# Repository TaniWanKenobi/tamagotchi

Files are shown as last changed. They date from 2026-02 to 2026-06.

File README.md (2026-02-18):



<p align="center">
  <a href="https://www.kicad.org">
    
  </a>
  <a href="https://www.onshape.com">
    
  </a>
</p>

<br />

<div align="center">
  Tamagotchi
</div>

<h3 align="center">Tamagotchi</h3>

<p align="center">
  A custom PCB-based Tamagotchi virtual pet built with the XIAO-ESP32-C6!
</p>

<details>
  <summary>Table of Contents</summary>
  <ol>
    <li>
      <a href="#about-the-project">About The Project</a>
      <ul>
        <li><a href="#built-with">Built With</a></li>
        <li><a href="#pcb-design">PCB Design</a></li>
        <li><a href="#3d-model">3D Model</a></li>
        <li><a href="#bom">BOM</a></li>
      </ul>
    </li>
    <li><a href="#contact">Contact</a></li>
  </ol>
</details>

## About The Project

<div align="center">
  CAD
</div>

A custom PCB-based Tamagotchi virtual pet built with the XIAO-ESP32-C6 microcontroller, featuring a 0.96" OLED display, three buttons, and a buzzer.

I made the project to have my own completely customizable tamagatchi! I also want you to customize yours however you want - check my [tutorial](/tutorial.md) for instructions! 

To use this, simply flash the xiao with the firmware in the repo! Here is an assembly diagram:

assembly

### PCB Design

Here is my PCB:

PCB

Front 3D model

Back 3D model

Here is the schematic used to make the PCB:

Schematic

### 3D Model

3D Model Front

Here is the [Onshape link](https://cad.onshape.com/documents/fa5791d8e7f345b436054923/w/ad8e09905eb572b0a8a40e9d/e/e81f06aa82a76dd04f8e6832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)!

### BOM

| Component | Qty | Price | Tax (6.7%) | Total | Link |
|---|-----|---|---|---|---|
| XIAO-ESP32-C6 | 1 | $5.20 | $0.35 | $5.55 | [Seeed Studio](https://www.seeedstudio.com/Seeed-Studio-XIAO-ESP32C6-p-5884.html) |
| Seeed Studio Shipping | 1 | $6.69 | $0.45 | $7.14 | — |
| 0.96" OLED Display | 1 | $2.15 | $0.14 | $2.29 | [LCSC](https://www.lcsc.com/product-detail/C5248080.html) |
| Tactile Button | 3 | $0.50 | $0.03 | $0.53 | [LCSC](https://www.lcsc.com/product-detail/C2888493.html) |
| Buzzer | 1 | $0.54 | $0.04 | $0.58 | [LCSC](https://www.lcsc.com/product-detail/C49246964.html) |
| Male Pin Headers (20 pcs) | 1 | $0.59 | $0.04 | $0.63 | [LCSC](https://www.lcsc.com/product-detail/C49261205.html) |
| LCSC Shipping | 1 | $14.73 | $0.99 | $15.72 | — |
| JLCPCB PCB | 1 | $5.40 | $0.36 | $5.76 | [JLCPCB](https://jlcpcb.com/) |
| JLCPCB Shipping | 1 | $3.30 | $0.22 | $3.52 | — |
| M3 8mm Screws | 1 | $2.28 | $0.15 | $2.43 | [AliExpress](https://www.aliexpress.us/item/3256809831708799.html) |
| Brass Threaded Inserts | 1 | $5.79 | $0.39 | $6.18 | [AliExpress](https://www.aliexpress.us/item/3256806286648221.html) |
| | | | | | |
| **Total** | | **$47.17** | **$3.16** | **$50.33** | |

## Contact

Tanishq Goyal - @Tanuki - [tanishqgoyal590@gmail.com](mailto:tanishqgoyal590@gmail.com)

<p align="right">(<a href="#readme-top">back to top</a>)</p>

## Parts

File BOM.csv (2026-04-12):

Item | Description | Quantity | Unit Price ($) | Total Price ($) | URL | Running Total ($ with Tax)
XIAO ESP32 C3 | MCU | 1 | $7.09 | $7.09 | https://www.aliexpress.us/item/3256808605622611.html | $7.56
Display | s | 1 | $1.93 | $1.93 | https://www.aliexpress.us/item/3256807544901434.html | $9.62
Headers | Headers | 1 | $1.69 | $1.69 | https://www.aliexpress.us/item/3256811506646304.html | $11.42
Buzzer | 12*9.5mm | 1 | $2.39 | $2.39 | https://www.aliexpress.us/item/3256810135642750.html | $13.97
Button | 4.5X4.5MM Button | 1 | $2.57 | $2.57 | https://www.aliexpress.us/item/3256806953793236.html | $16.71
Threaded Inserts | M3X4X5 | 1 | $2.47 | $2.47 | https://www.aliexpress.us/item/3256811754262338.html | $19.34
Screws | M3, 8mm | 1 | $2.23 | $2.23 | https://www.aliexpress.us/item/3256809831708799.html | $21.72
Shipping | Aliexpress | 1 | $2.53 | $2.53 | https://www.aliexpress.us/ | $24.42
PCB | JLCPCB | 1 | $3.20 | $3.20 | https://jlcpcb.com/ | $27.83
Shipping | JLCPCB | 1 | $3.12 | $3.12 | https://jlcpcb.com/ | $31.16

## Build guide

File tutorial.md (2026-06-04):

# Tamagotchi PCB Tutorial

> **Note:** Your schematic should NOT look like this at the end of the tutorial! You are required to add your own components and switch it up to personalize it :D

---

## Table of Contents

- [Installing KiCad](#installing-kicad)

### 1. Schematic Design
- [Creating the Schematic](#creating-the-schematic)
  - [Importing the MCU](#importing-the-mcu)
  - [Adding the OLED Display](#adding-the-oled-display)
  - [Adding Buttons](#adding-buttons)
  - [Adding a Buzzer](#adding-a-buzzer)
  - [Power & Battery Setup](#power--battery-setup)
  - [Assigning Footprints](#assigning-footprints)

### 2. PCB Design
- [Creating the PCB](#creating-the-pcb)
  - [Defining the Board Outline](#defining-the-board-outline)
  - [Component Placement](#component-placement)
- [Button Footprint Mismatch](#button-footprint-mismatch)
- [PCB Routing](#pcb-routing)
  - [Routing Traces](#routing-traces)
- [Customization](#customization)
- [Run Design Rules Check](#run-design-rules-check)
  - [Common DRC Errors](#common-drc-errors)

### 7. Files & Version Control
- [Add Your Files to Your GitHub Repo](#add-your-files-to-your-github-repo)
- [Upload Your Files to GitHub](#upload-your-files-to-github)
  - [Edit Your README](#edit-your-readme)

### 8. Fabrication
- [Getting a JLCPCB Price](#getting-a-jlcpcb-price)
  - [Settings](#settings)

### 9. Enclosure Design
- [Designing the Case](#designing-the-case)

---

## Installing KiCad

Download KiCad from the official site: **[https://www.kicad.org/download/](https://www.kicad.org/download/)**

1. Go to the download page and select your operating system (Windows, macOS, or Linux).
2. Download the latest **stable release** (KiCad 10.x).
3. Run the installer and follow the on-screen instructions (the defaults are fine).
4. When prompted, make sure to **install the default libraries** (they're selected by default).
5. Launch KiCad and create a new project (**File → New Project** or **Ctrl+N**).

What are the default libraries?

> KiCad ships with a large set of schematic symbols, PCB footprints, and 3D models. These cover most common components (resistors, capacitors, connectors, etc.) so you don't have to create them from scratch. You'll still need to import specialty parts (like the XIAO or OLED), but the defaults cover the basics.

> **New to KiCad?** Read the official getting started guide before continuing:
> [KiCad 10.0: Getting Started](https://docs.kicad.org/10.0/en/getting_started_in_kicad/getting_started_in_kicad.html)

---

## Creating the Schematic

The XIAO-ESP32-C3 will be used as the MCU in this guide! This is because it's tiny and includes WiFi, Bluetooth, and built‑in battery charging, which makes it perfect for this.

What is an MCU?

> MCU stands for **Microcontroller Unit**, the tiny computer (brain) of your project. It runs your code and controls all the other components (display, buttons, buzzer, etc.). The XIAO-ESP32-C3 is the MCU we're using here.
>
> That said, other MCUs are worth knowing about. The RP2040 is a good pick if you don't need wireless: dual-core, and has really good documentation! The nRF52840 is the go-to for low power BLE projects, with sleep currents that blow the ESP32 out of the water. For this project the C3 wins because it's affordable, has WiFi and BLE built in, and includes onboard LiPo charging so no external charger chip is needed.I use the C3 for those reasons.

Useful schematic editor keybinds

> | Key | Action |
> |-----|--------|
> | **A** | Add a symbol (component) |
> | **W** | Draw a wire |
> | **P** | Add a power symbol (VCC, GND, 3V3, etc.) |
> | **L** | Add a net label |
> | **M** | Move a component |
> | **R** | Rotate a component |
> | **G** | Grab/drag a component (keeps wires attached) |
> | **E** | Edit component properties |
> | **C** | Copy a component |
> | **Delete** | Delete selected item |
> | **Ctrl+Z** | Undo |
> | **Ctrl+S** | Save |

### Importing the MCU

First, I imported the XIAO-ESP32-C3 from the [SeeedStudio Wiki](https://wiki.seeedstudio.com/XIAO_ESP32C3_Getting_Started/). Here's an [excellent tutorial](https://www.youtube.com/watch?v=lnCvyGIQong) on using it!

I downloaded from this:



I then clicked **A** (Add Symbol), searched for the part, and imported it. I ended up with this:

Xiao

Most symbols won't label every pin with its function (SDA, SCL, MOSI, etc.) They'll just show pin numbers. When that happens, google the MCU name + "pinout" to find the official diagram and cross-reference which pin number maps to which function :D 

**Now, for this tutorial, I will create the base Tamagotchi. Spice your own Tamagotchi up more than this one! Add some flavor!**

I then connect GND to GND, 5V to +5V, 3V3 to  and BAT to + as shown below:

Power connections

## What is 5V? What is GND? What is 3V3?

> #### What "ground" actually means here
>
> Ground is the **reference point** for the entire circuit.
> Think of it as the **zero level** that everything else is measured against.
>
> - Voltage is always measured **relative to ground**.
> - Current flows **from power, through components, back to ground**.
> - Without ground, the circuit has **no return path**, so nothing works.
>
> Ground isn't "negative energy"; it's simply the **other side of the loop**.
>
> [Check this for more information!](https://www.build-electronic-circuits.com/what-is-ground/)
>
> Additionally, here's some ground!
>
> grass
>
> #### What voltage is, and why it matters
>
> Voltage is the **electrical pressure** that pushes electrons through the circuit.
>
> - Higher voltage = stronger push
> - Lower voltage = weaker push
>
> Voltage matters because every component is designed to operate within a certain range.
>
> [Check this for more information!](https://battlebornbatteries.com/what-are-volts/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)
>
> low-voltage
>
> #### 5V vs 3V3, why two rails?
>
> The XIAO exposes two voltage rails: **5V** and **3V3**.
>
> - **5V** is powered by USB-C. When running on battery, the LiPo only outputs ~3.7V, not enough to supply this pin, so it gets no power.
> - **3V3** is a stable 3.3V generated on-board, available whether you're on USB or battery.
>
> Most components, the OLED, sensors, logic pins, are rated for **3.3V**, so connect them to 3V3. Too much voltage means too much current, which damages components. 

**Why didn't I connect the top pads?**



I didn't connect them because I don't need JTAG debugging for this project. A JTAG debug cable is a special cable that connects your computer to these pads, letting you pause your program mid-run and inspect exactly what's happening inside the chip line by line. USB-C handles everything we need here.

You may use them if you want, but I didn't because it would complicate the PCB for not much benefit. You might want to use them if you have a really tricky bug that Serial printing can't help you catch, or if you run out of GPIO pins and need extras.

### Adding the OLED Display

I then added the [0.96" OLED](https://www.lcsc.com/product-detail/C5248080.html) via EasyEDA to KiCad. Follow this [guide](https://hwdocs.hackclub.dev/user-contrib-guides/easyeda2kicad/)!

I connected GND to GND, SDA to SDA, and SCL to SCL. Use **W** to draw wires between pins!

What are SDA, SCL, and GND?

> - **GND** = Ground, the common reference point for all electrical signals.
> - **SDA** = Serial Data, the line that carries data back and forth over I2C.
> - **SCL** = Serial Clock, the line that provides the timing signal for I2C communication.
>
> I2C is a protocol that lets multiple devices talk over just two wires (SDA + SCL).

Do I need pull-up resistors on SDA and SCL?

> Normally yes. I2C requires pull‑up resistors on SDA and SCL; however, the XIAO boards already include internal pull‑ups, so you don't need external ones here.

I checked the [datasheet](https://www.lcsc.com/datasheet/C5248080.pdf) attached on the LCSC page and found that VCC should be connected to 3V3.



I therefore connected it as such



### Adding Buttons

Since a Tamagotchi has three buttons, I decided to add those as well!

For this, I decided to use an **active‑low** button layout (which is the most common approach).

What does "active-low" mean?

> "Active-low" means the button is considered "pressed" when the signal goes LOW (0V / GND). When the button is not pressed, the internal pull-up resistor keeps the pin HIGH (3.3V). This is the most common button wiring approach because it's simple: you only need the button and a ground connection, no extra resistors.

Each button connects one side to **GND** and the other to a **GPIO pin** with the XIAO's **internal pull‑up** enabled. This makes the pin read **HIGH** when the button is idle, and **LOW** when the button is pressed.



What is a GPIO pin?

> GPIO stands for **General Purpose Input/Output**. These are the programmable pins on your microcontroller that can be configured as either inputs (to read sensors/buttons) or outputs (to drive LEDs/buzzers). On the XIAO, pins like D0–D10 are GPIOs.

### Adding a Buzzer

I also added a buzzer from [here](https://www.lcsc.com/product-detail/C49246964.html)!

The buzzer is wired with one pin to a GPIO output and the other to GND, letting the GPIO drive it with a square‑wave tone.



### Power & Battery Setup

I then added the battery.

The XIAO ESP32C3 has built-in battery charging, so all you need to do is connect a LiPo battery directly to the BAT pin. This lets the board run wirelessly and automatically charges the battery whenever you plug in USB-C.

BAT is connected only to the battery because it is a dedicated charging pin, separate from the main 3.3V power rail. GND however is shared across everything on the board, since all components need a common ground reference to work correctly.



> **Don't forget to place no-connect flags where there aren't connections!**

Press `Q` → click the pin to place the no-connect flag



> **Note:** In schematics, inputs are generally placed on the left and outputs on the right. This is a common convention that makes your schematic easier to read, since signal flow goes left to right just like reading a book. You don't have to follow this strictly, but it is good practice to keep things consistent!

### Assigning Footprints

This is my final schematic! Let's make the PCB now. First, let's assign parts. Click this:



Then assign the corresponding EasyEDA / OPL parts! For the buttons, import from [here](https://www.lcsc.com/product-detail/C2888493.html)!

1. **Battery connector:** I use 2.54mm male headers, since 2.54mm is the standard pin spacing used on most hobby electronics and battery connectors.
2. **Buzzer:** According to the [AliExpress listing](https://www.aliexpress.us/item/3256810135642750.html) I am ordering from, the buzzer is 12x9.5mm, where 12mm is the diameter and 9.5mm is the pin spacing. This fits the `Buzzer_12x9.5RM7.6` footprint. Note that the EasyEDA buzzer footprint uses a pin spacing of 7mm instead of 9.5mm, so make sure to use the correct one!
3. **Buttons:** Imported from the link above.
4. **XIAO:** I use a mix of SMD and DIP footprint from the [footprint library](https://files.seeedstudio.com/wiki/XIAO-KiCad-Library/New_XIAO_Series_Footprints.zip) linked earlier. I will later modify the footprint so the SMD pads are through-hole, allowing me to solder the XIAO directly by melting solder into the pads. The name of this footprint is `XIAO-ESP32-C3-DIP-SMD`.
5. **OLED:** Imported from EasyEDA using the link from earlier.

Footprint assignment

Now, press this and open the PCB viewer:

Open PCB viewer

---

## Creating the PCB

**The maximum size of your PCB should be 100mm²!**

You should see something like this:

PCB editor

To synchronize changes between your schematic and PCB layout in KiCad:

- Press **F8**, *or*
- Click the **Update PCB from Schematic** button

You can do this anytime you want to refresh the PCB with the latest schematic updates.

What are those two circles?
> Those are M3 mounting holes! Click A to add them!

### Defining the Board Outline

You'll notice a white outline surrounding the entire board. This is the **Edge Cuts** layer, which defines the physical boundary where the PCB will be cut.

This is done by modifying the `Edge.Cuts` layer on the right side. There are many ways to do this, such as manually drawing it with the given menu.

I found the default outline options limiting and wanted to create something more complex. To do this, I:

1. Drew out the edge cuts layer. I just did this on figma, you can do this anywhere!!!
2. Converted the image into a DXF file using an image-to-DXF converter.
3. Imported the DXF file into KiCad.
4. Created a 100×100 mm box as a reference.
5. Used the measuring tool to determine the correct scale.
6. Scaled the outline down so it fit within 100 mm.

cutout

You can also use the kicad tools on the right to draw a barrier, they work well! I just wanted to make a cool and unique border. You should try it!



### Component Placement

**First, I laid my PCB out in a 100×100 box.**

Place all of your components inside the board outline. Move components to shorten **ratlines**, which are the straight blue lines.

- **M**: Move a component
- **R**: Rotate a component
- **F**: Flip a component to the other side of the board
- **Ctrl+S** / **⌘+S**: Save (do this often!)

What are ratlines?

> Ratlines (also called "ratsnest lines") are the thin straight lines that show unrouted connections between pads. They indicate which pads need to be connected with copper traces. Your goal is to arrange components so these lines are as short as possible and don't cross each other, which makes routing much easier.

Heres what I ended up with!



---

## Button Footprint Mismatch

> **Always verify your footprint before finalizing your PCB layout.** Even if a component looks correct in the schematic, the footprint may have incorrect pad numbering that causes your circuit to fail silently. A common red flag: any pin without a net almost always means something went wrong during import.

### Why This Happens

After importing a button from EasyEDA into KiCad, the footprint may look fine at first glance:

KiCad imported switch footprint

EasyEDA uses a **redundant 4-pin symbol**, showing all four pins separately even though two pairs are internally shorted:

EasyEDA button symbol

KiCad uses a **cleaner 2-pin representation**:

KiCad button symbol

When imported, EasyEDA's pins 1 and 2 map to opposite footprint pads, but on a tactile switch they're on the **same physical side** (internally shorted). This means pads that should be electrically separated end up sharing a net, and the button does nothing because one side is permanently shorted to itself.

| EasyEDA pins | Physical side | KiCad net |
|:---:|:---:|:---:|
| 1, 2 | Side A (shorted) | Net 1 |
| 3, 4 | Side B (shorted) | Net 2 |

The switch connects **Side A to Side B** when pressed. The footprint must reflect this.

### Confirming with the Datasheet

Verify the pinout using the component's datasheet. If sourcing from LCSC, the datasheet is available directly on the product page. For example:

- [Product page](https://www.lcsc.com/product-detail/C2888493.html)
- [Datasheet](https://www.lcsc.com/datasheet/C2888493.pdf)

Physical pin diagram
Internal schematic

These confirm that **pads 1 and 2 are shorted** (Side A) and **pads 3 and 4 are shorted** (Side B).

### Fixing the Pad Numbering

Renumber the footprint pads to match the correct mapping:

- Pads **1 and 2** (same physical side) → renumber both to **`1`**
- Pads **3 and 4** (other physical side) → renumber both to **`2`**

1. Double-click the footprint in the PCB editor and click **Edit Library Footprint**.

Edit Library Footprint dialog

2. Double-click each pad hole and update the pad number to match the corrected mapping:

Corrected pad numbering

3. Press `Ctrl+S` to save.

### Applying the Fix

1. Go to **Tools > Update Footprint from Library**.

Update Footprint from Library menu

2. Click **Update**.

The footprint will refresh with the corrected pad numbering: one net on Side A, a separate net on Side B, and the switch bridging them when pressed.

> Does this not work? Try deleting the buttons, and updating from schematic again :)



We do something similar to the XIAO footprint.

Xiao

Double click each BAT pad, set it to through-hole (THT), and give it a drill diameter of 0.889mm.

Fixing Footprint

You may also notice that similar to the buttons, the pin numbers are wrong according to the official Seeed diagram:

Footprints

Fix the pin numbers to match. Keep in mind that the footprint is mirrored, so if it helps, temporarily move it to the back layer so it is orientated the same way as the diagram.

Here are some useful diagrams!





Here is the final result:

Final result

Save and update your PCB from schematic when done!

---

## PCB Routing

A PCB is made up of multiple layers. Our boards are "two-layer," meaning that they have two layers of copper wire.

What are the PCB layers?

> | Layer | Description |
> |-------|-------------|
> | **Top & bottom silkscreen** | The white ink layer where you can add art |
> | **Top & bottom copper** | The layers where you make your copper wires |
> | **Substrate** | The actual plastic (usually green) which makes up your board |
> | **Via** | The tunnels which connect the top and bottom copper layers |
>
> PCB layers

### Routing Traces

Now it's time to route the PCB! Hit **X** on your keyboard and click anything with a thin blue line poking out of it. It should dim the entire screen, show you which direction you need to go with a thin blue line, and highlight the destination:

Routing example

**Key routing shortcuts:**

- **X**: Start routing a trace
- **V**: Add a via (switch trace to the other side of the board mid-route)
- **Backspace**: Delete the last trace segment while routing
- **Esc**: Cancel the current route
- **D**: Drag a trace (reposition it without breaking connections)
- **U**: Select the entire trace from the point you click

Join the highlighted points together. If there isn't enough space on the front side, or there is a trace already present that is blocking you, you can route on the back side by clicking **B.Cu** on the right toolbar. If you want to change sides during routing, press **V** and a via will be added, which will transfer your trace to the other side of the board.

> **Important:** Wires and pads of different colors (except golden) can't be connected together directly! You must use a via to the other side.

What is a via?

> A via is a small plated hole that connects a copper trace on one layer of the board to a trace on another layer. Think of it as a tiny tunnel through the PCB. You use them when you can't route a trace on one side because another trace is in the way. Press **V** while routing to drop a via and continue the trace on the other side.

Your routing is complete!

Ground plane

> **Tip:** Place everything based on what shortens the blue lines, and what makes them not cross!

> **Tip:** Use a [ground plane](https://www.kicadtips.com/how-to/make-a-ground-plane) to help with routing and to reduce noise. That's what the red and blue layers are for! It's not necessary, but looks nice and is easy to set up!

> **Note:** You may notice [stitching vias](https://resources.altium.com/p/everything-you-need-know-about-stitching-vias) in my board (the small holes scattered across the ground plane). **You do NOT need to add these.** They are completely optional for a board like this!
>
> Stitching vias

---

## Customization

You may have already added some text and art to customize your board like me. If not, you can click **F.Silkscreen** and use the text tool.

Sample text

To add art, select the **Top Silkscreen Layer** or **Bottom Silkscreen Layer** in the sidebars, then use the KiCad image converter to add custom art.

KiCad image converter

Your board is now beautiful! 

---

## Run Design Rules Check

**DRC** stands for **Design Rules Check**. This runs a check that makes sure your board has no interference errors, no components are off the board, and no wires are intersecting. It does **not**, however, confirm that your board works.

DRC

Using the output, correct any errors. This can be confusing, so remember: you can always ask for help!

What are common DRC errors?

> - **Track and copper errors** : clearance violations, track width, annular rings
> - **Via errors** : diameter, micro vias, blind/buried vias
> - **Pad and footprint errors** : pad-to-pad, hole clearances
> - **Edge and board outline errors** : copper edge clearance, silkscreen issues
> - **Zone errors** : copper slivers, starved thermals, unconnected items
> - **Net and connection errors** : missing connections, net conflicts
> - **Courtyard errors** : overlaps, missing courtyards

Once your PCB passes the DRC, it is finished!

In the PCB editor, click **View → 3D Viewer** to see your finished work!

3D Viewer

> Final

---

## Add Your Files to Your GitHub Repo

Now it is time to order your board. Get the following files from your project:

- **A screenshot of your 3D view**
  - In PCB Editor: **View → 3D Viewer → Edit → Copy 3D Image**
- `.kicad_pro` (KiCad project file)
- `.kicad_sch` (schematic)
- `.kicad_pcb` (PCB layout)
- **Your Gerber files** (see below)

How do I export Gerber files?

> 1. In your PCB editor: **File → Fabrication Outputs → Gerbers (.gbr)**
> 2. Set an output folder (e.g., a new "Gerbers" folder)
> 3. Select necessary layers (generally already selected)
> 4. Click **Plot**
> 5. Click **Generate Drill Files**
> 6. Zip the resulting files for your manufacturer
>
> Gerber files are the industry-standard format that PCB manufacturers use to fabricate your board. They contain the copper layers, silkscreen, solder mask, drill locations, and board outline.

---

## Upload Your Files to GitHub

Go back to the GitHub repo you created at the start. Click **Add File → Upload files**.

Drag in your:

- Screenshot of your 3D view
- `.kicad_pro` (KiCad project file)
- `.kicad_sch` (schematic)
- `.kicad_pcb` (PCB layout)
- Gerbers (zipped)

You should have downloaded all of these in the previous step.

Click to commit your changes.

### Edit Your README

Finally, edit your README to include the submission requirements:

- A short description of what your project is
- A couple sentences on why you made the project
- A couple sentences on how to use your project

**Pictures of your project:**

- A screenshot of a full 3D model of your project
- A screenshot of your PCB, if you have one
- A wiring diagram, if you're doing any wiring that isn't on a PCB

**A BOM (Bill of Materials) in table format at the end of the README, with links.**

> **NOTE:** ALL projects you make for Blueprint must have a project photo in your README.

---

## Getting a JLCPCB Price

Go to [jlcpcb.com](https://jlcpcb.com/) and make an account. Then, add your Gerber file for the instant quote.

JLCPCB upload

### Settings

You should keep the default settings for everything. The only thing you should/can change is the **PCB Color**. I did black as seen below:

PCB color

For high-spec options, also keep the default. **Do not** click PCB assembly! 

High-spec options

Once you have successfully *not* changed any of the settings (except the board color), on the right, change the shipping method to **Global Standard Direct** (or **Air Registered Mail** if it is cheaper).

---

## Designing the Case

Export the PCB from KiCad into your CAD platform! For me, this is Onshape.

**Check [this amazing onshape tutorial](https://www.youtube.com/watch?v=d4QzBdcQoe0&list=PLGqRUdq5ULsMDOxmu10AGPDIOkzNYu7D7&index=2)!**

I googled and found headers! I found this from [here](https://www.3dcontentcentral.com/download-model.aspx?catalogid=171&id=1025256)!

I then experimented with the CAD a lot. I used revolve, but it did not look nice and was hard to use. I also tried multiple placements for the battery and found it was optimal if it's placed vertically.

To make these, I created a sketch by clicking the sketch button in the upper-left-hand side and made multiple shapes that include tolerance and my shell size.







I also decided to change the PCB to add the vibration motor to the back and raise the screen!

From



to



My headers overlapped with the buzzer, so I decided to reposition the buzzer to the middle of the board! The gap between the LCD and the headers should give me enough space!

example

I made the back portion with 3D-printed standoffs and added large fillets to round the edges. I made the top part and added some tolerance between the top of the plate and the bottom of the top half of the case!



I added a hole for the battery and a hole for the USB-C. Generally, there may be issues printing this, but for this small amount of bridging there shouldn't be any issues!

I also made sure to add an offset to the USB C! The USB-C I measured with my calipers was 7 mm x 13 mm about, would reccomend making it bigger just in case by ~ 1 mm. If you have a 3d printer, you can just test values yourself! My values worked for me (12.5 x 7.5 mm, athough they are pretty tight, **I would def make it a little bigger**)





Finally, I used the section view tool to confirm that there is no overlapping:



Now, my design is finished! I uploaded all necessary files to my GitHub repo. 

**Note: Design is an iterative process. I spent about 20+ hours manually adjusting everything to look as pretty as possible! But don't worry, #fallout is here to guide you! This is a normal process and you are not alone.**

I recommend **not** following the above 1:1; this was my process, and it will differ greatly from yours!

I also recommend checking my [Onshape](https://cad.onshape.com/documents/fa5791d8e7f345b436054923/w/ad8e09905eb572b0a8a40e9d/e/e81f06aa82a76dd04f8e6832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) for inspiration! Check my feature tree and see my iterations yourself.

> **A Note:**
>
> This project took me way longer than expected, and that's completely normal.
>
> My 3D printer wouldn't connect to the network, then had config issues once it did. I spent hours trying to flash my XIAO to the wrong COM port before realizing the flashing process had changed. A button stopped working after soldering, and while trying to fix it I accidentally shorted something on the XIAO, which took a few more hours to debug and desolder.
>
> None of this means you did something wrong. You got this!
>
> The biggest thing I learned: if you're stuck on something that feels like it's eating hours with no end in sight, it's often faster to find a completely different approach than to keep pushing through. Flashing not working? Try a different method. Component not desoldering cleanly? Maybe there's a workaround that doesn't require removing it at all. The path forward usually exists, it just might not be the one you started on.
>
> You've got the whole Fallout community to ask for help :D

Enjoy making :D!

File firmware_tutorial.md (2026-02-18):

# Firmware Setup Tutorial

First, install the [Arduino IDE](https://www.arduino.cc/en/software/).

<details>
<summary>What is Arduino IDE?</summary>

Arduino IDE is used to edit sketches and upload them to boards like the [ESP32-C6](https://www.espressif.com/en/products/socs/esp32-c6) over USB.

</details>

---

## Table of Contents

- [Step 1: Install the ESP32 Board Package](#step-1-install-the-esp32-board-package)
- [Step 2: Install the Board in Boards Manager](#step-2-install-the-board-in-boards-manager)
- [Step 3: Select the Board and Port](#step-3-select-the-board-and-port)
- [Step 4: Install Required Libraries](#step-4-install-required-libraries)
- [Step 5: Create the Project](#step-5-create-the-project)
- [Step 6: Reading Your Schematic for Firmware](#step-6-reading-your-schematic-for-firmware)
- [Step 7: Includes and Hardware Configuration](#step-7-includes-and-hardware-configuration)
- [Step 8: Define the Pet Model](#step-8-define-the-pet-model)
- [Step 9: Define UI States (State Machine)](#step-9-define-ui-states-state-machine)
- [Step 10: Setup Function](#step-10-setup-function)
- [Step 11: Game Update Logic](#step-11-game-update-logic)
- [Step 12: Reading Button Input](#step-12-reading-button-input)
- [Step 13: Screen Logic](#step-13-screen-logic)
- [Step 14: Pet Sprites](#step-14-pet-sprites)
- [Step 15: Display Function (OLED Rendering)](#step-15-display-function-oled-rendering)
- [Step 16: Main Loop](#step-16-main-loop)

---

## Step 1: Install the ESP32 Board Package

ESP32 support isn't included by default, so you need to add Espressif's board package URL.

1. Open the Arduino IDE.
2. Go to **File > Preferences** (or **Arduino IDE > Settings** on macOS).
3. In the **"Additional Boards Manager URLs"** field, add the following URL:
   ```
   https://espressif.github.io/arduino-esp32/package_esp32_index.json
   ```
   > **Note:** If you already have URLs here, separate entries with commas.
4. Click **OK** to save the preferences.
5. Wait for the board index to download.

<details>
<summary>Why this step?</summary>

This URL provides Arduino with Espressif's board definitions and the tools needed to compile and upload.

</details>

## Step 2: Install the Board in Boards Manager

1. Open the **Boards Manager** by navigating to **Tools > Board > Boards Manager**.
2. In the search bar, type `esp32`.
3. Locate the entry for **"esp32 by Espressif Systems"**.
4. Click the **Install** button.
   > **Important:** Ensure you are using version **3.0.0 or later**, which supports the C6.
5. Wait for the installation to finish.

<details>
<summary>What gets installed?</summary>

It installs the [RISC-V](https://en.wikipedia.org/wiki/RISC-V) cross-compiler toolchain, ESP-IDF libraries, and upload tools.

</details>

## Step 3: Select the Board and Port

1. After installation, go to **Tools > Board > esp32**.
2. Select your board model: `XIAO ESP32C6`.

<details>
<summary>Why does the board selection matter?</summary>

The selected board controls default pin mappings and build settings (flash size, bootloader, clock speed).

</details>

## Step 4: Install Required Libraries

In **Sketch > Include Library > Manage Libraries**, install:

1. **Adafruit SSD1306** (by Adafruit)
2. **Adafruit GFX Library** (by Adafruit), which will be prompted as a dependency.

<details>
<summary>What are these libraries for?</summary>

- **Adafruit SSD1306**: SSD1306 OLED driver (I2C).
- **Adafruit GFX**: drawing primitives used by the driver.

</details>

## Step 5: Create the Project

Create a new Arduino sketch: **File > New Sketch**, then save it as `Tamagotchi.ino`.

<details>
<summary>What is a .ino file?</summary>

Arduino treats `.ino` as C++. The IDE adds `Arduino.h` and generates `main()`, so sketches only need to implement [`setup()`](https://docs.arduino.cc/language-reference/en/structure/sketch/setup/) and [`loop()`](https://docs.arduino.cc/language-reference/en/structure/sketch/loop/).

</details>

---

## Step 6: Reading Your Schematic for Firmware

Before writing any code, open your `.kicad_sch` and confirm each component's connections to the MCU. Your pin mappings in firmware must match the schematic.

Trace each component to the MCU and record the GPIO number. KiCad shortcut: click a wire and press **`** (backtick) to highlight the net.

### My Results

Example pin mapping from my schematic (yours will differ):

**Buttons** (active-low: one side to GND, other side to MCU → reads `LOW` when pressed):

| Button | MCU Pin | GPIO |
|---|---|---|
| SW1 | Pin 1 | GPIO0 |
| SW2 | Pin 2 | GPIO1 |
| SW3 | Pin 3 | GPIO2 |

**OLED Display** (I²C address is usually `0x3C`, check your datasheet):

| OLED Pin | MCU Pin | GPIO |
|---|---|---|
| SDA | Pin 5 | GPIO22 |
| SCL | Pin 6 | GPIO23 |

**Buzzer** (positive terminal tied 3.3V to GPIO **sinks** current, so `LOW` = ON):

| Buzzer Pin | MCU Pin | GPIO |
|---|---|---|
| Signal | Pin 10 | GPIO20 |

<details>
<summary>How do I know if my buzzer is active or passive?</summary>

- **Active buzzer**: has an internal oscillator. Turn it on/off with a digital signal.
- **Passive buzzer**: requires a driven waveform. Control pitch with `tone()`.

Check the datasheet or distributor listing. Active buzzers typically mention an internal oscillator; passive ones don't.

</details>

### Turn Your Results into Code

Define the GPIOs at the top of your sketch:

```cpp
// Buttons (traced from schematic)
#define BTN1 0   // SW1 → MCU Pin 1 → GPIO0
#define BTN2 1   // SW2 → MCU Pin 2 → GPIO1
#define BTN3 2   // SW3 → MCU Pin 3 → GPIO2

// I2C OLED (traced from schematic)
#define SDA_PIN 22  // OLED SDA → MCU Pin 5 → GPIO22
#define SCL_PIN 23  // OLED SCL → MCU Pin 6 → GPIO23

// Buzzer (traced from schematic)
#define BUZZER 20   // Buzzer signal → MCU Pin 10 → GPIO20
```

Use the GPIO numbers from your schematic. If these `#define`s don't match your wiring, the firmware will compile but the hardware won't behave correctly.

---

## Step 7: Includes and Hardware Configuration

Add the required includes and configure the display and pin constants.

```cpp
#include <Wire.h>
#include <Adafruit_GFX.h>
#include <Adafruit_SSD1306.h>

#define SCREEN_WIDTH 128
#define SCREEN_HEIGHT 64
#define OLED_RESET -1

Adafruit_SSD1306 display(SCREEN_WIDTH, SCREEN_HEIGHT, &Wire, OLED_RESET);

#define BTN_LEFT   D0
#define BTN_MIDDLE D1
#define BTN_RIGHT  D2
#define BUZZER_PIN D3
```

**Notes:**

- `#include <Wire.h>` includes the [I2C library](https://docs.arduino.cc/language-reference/en/functions/communication/wire/), which handles communication with the OLED over the SDA/SCL pins.
- `#include <Adafruit_GFX.h>` and `#include <Adafruit_SSD1306.h>` bring in the display driver and graphics functions.
- `SCREEN_WIDTH` / `SCREEN_HEIGHT` match the 0.96" OLED resolution (128x64 pixels).
- `OLED_RESET` is set to `-1` because our OLED does not have a dedicated reset pin.
- `Adafruit_SSD1306 display(...)` creates the display object we'll use to draw everything.
- `BTN_LEFT`, `BTN_MIDDLE`, `BTN_RIGHT` are the GPIO pins connected to the buttons. Set these to match your schematic.
- `BUZZER_PIN` is the GPIO connected to the buzzer.

<details>
<summary>What if my buttons are on different pins?</summary>

Check your KiCad schematic to see which GPIO pins your buttons are wired to. Then change `D0`, `D1`, `D2`, and `D3` to match. For example, if your left button is on pin D5, change the line to `#define BTN_LEFT D5`.

</details>

## Step 8: Define the Pet Model

Define a [`struct`](https://cplusplus.com/doc/tutorial/structures/) to store the pet's stats.

```cpp
struct Pet {
  int hunger;       // 0 to 100 (0 = starving, 100 = full)
  int happiness;    // 0 to 100 (0 = miserable, 100 = ecstatic)
  int energy;       // 0 to 100 (0 = exhausted, 100 = fully rested)
  unsigned long age; // total seconds the pet has been alive
};
```

**Notes:**

- `struct Pet { ... };` defines a `Pet` type with fields for the pet's stats.
- `int hunger;` is an integer from 0 to 100. We chose `int` because the values are small whole numbers.
- `unsigned long age;` uses [`unsigned long`](https://docs.arduino.cc/language-reference/en/variables/data-types/unsignedLong/) (0 to 4,294,967,295) because time values from `millis()` can get very large and are never negative.

Create one global instance:

```cpp
Pet pet;
```

<details>
<summary>Why global?</summary>

A [global variable](https://docs.arduino.cc/language-reference/en/variables/variable-scope-qualifiers/scope/) lets `setup()`, `loop()`, and helpers share the same state.

</details>

## Step 9: Define UI States ([State Machine](https://en.wikipedia.org/wiki/Finite-state_machine))

Define named states for the UI using a finite state machine. The program is always in exactly one state.

```cpp
enum Screen {
  SCREEN_MAIN,
  SCREEN_FEED,
  SCREEN_PLAY,
  SCREEN_SLEEP
};

Screen currentScreen = SCREEN_MAIN;
```

**Notes:**

- `enum Screen { ... };` is an [`enum`](https://cplusplus.com/doc/tutorial/other_data_types/) (enumeration) that assigns human-readable names to integer constants. Under the hood, `SCREEN_MAIN` = 0, `SCREEN_FEED` = 1, etc., but we never need to know that.
- `Screen currentScreen = SCREEN_MAIN;` tracks which screen we're on right now. The program starts on the main screen.

<details>
<summary>Why use a state machine?</summary>

Without it, you end up with deeply nested `if` statements that are hard to read and debug. A state machine makes the logic predictable: *"When I'm in state X and event Y happens, go to state Z."* This is the same pattern used in [real embedded systems](https://en.wikipedia.org/wiki/UML_state_machine), game engines, and protocol parsers.

</details>

## Step 10: Setup Function

[`setup()`](https://docs.arduino.cc/language-reference/en/structure/sketch/setup/) runs **once** when the board powers on or resets. Use it to initialize the display, buttons, and starting values.

```cpp
void setup() {
  pinMode(BTN_LEFT, INPUT_PULLUP);
  pinMode(BTN_MIDDLE, INPUT_PULLUP);
  pinMode(BTN_RIGHT, INPUT_PULLUP);
  pinMode(BUZZER_PIN, OUTPUT);

  display.begin(SSD1306_SWITCHCAPVCC, 0x3C);
  display.clearDisplay();
  display.setTextSize(1);
  display.setTextColor(SSD1306_WHITE);
  display.setCursor(0, 0);
  display.println("Tamagotchi Init...");
  display.display();
  delay(1000);

  pet.hunger = 80;
  pet.happiness = 80;
  pet.energy = 80;
  pet.age = 0;
}
```

**Notes:**

- `pinMode(BTN_LEFT, INPUT_PULLUP);` configures each button pin as an input with the [internal pull-up resistor](https://docs.arduino.cc/language-reference/en/functions/digital-io/pinMode/) enabled. This means the pin reads `HIGH` normally and `LOW` when the button is pressed (active-low).
- `pinMode(BUZZER_PIN, OUTPUT);` sets the buzzer pin as an output so we can drive it with a signal.
- `display.begin(SSD1306_SWITCHCAPVCC, 0x3C);` initializes the OLED. `0x3C` is the [I2C address](https://learn.adafruit.com/adafruit-gfx-graphics-library) of the display (the most common address for these OLEDs).
- `display.clearDisplay();` clears any leftover data in the display buffer.
- `display.setTextSize(1);` sets text to the smallest size (6x8 pixels per character).
- `display.setTextColor(SSD1306_WHITE);` sets the drawing color to white (lit pixels).
- `display.println(...)` writes text to the **buffer** (not the screen yet).
- `display.display();` pushes the buffer to the actual OLED screen. **You must call this for anything to appear!**
- Stats start at 80/100, leaving room for improvement or decay.

<details>
<summary>What if my OLED doesn't turn on?</summary>

The most common issues are:
- **Wrong I2C address**: Some OLEDs use `0x3D` instead of `0x3C`. Try changing the address in `display.begin()`.
- **Wiring**: Double-check that SDA, SCL, VCC (3V3), and GND are connected correctly.
- **Library not installed**: Make sure you installed both Adafruit SSD1306 and Adafruit GFX.

</details>

## Step 11: Game Update Logic

Stats decay over time using [`millis()`](https://docs.arduino.cc/language-reference/en/functions/time/millis/) instead of [`delay()`](https://docs.arduino.cc/language-reference/en/functions/time/delay/). `delay()` blocks the entire program; `millis()` lets input and rendering continue.

```cpp
unsigned long lastUpdate = 0;

void updatePet() {
  if (millis() - lastUpdate > 5000) {  // every 5 seconds
    pet.hunger--;
    pet.happiness--;
    pet.energy--;

    if (pet.hunger < 0) pet.hunger = 0;
    if (pet.happiness < 0) pet.happiness = 0;
    if (pet.energy < 0) pet.energy = 0;

    pet.age += 5;
    lastUpdate = millis();
  }
}
```

**Notes:**

- `unsigned long lastUpdate = 0;` remembers the last time we updated the pet. Starts at 0 (boot time).
- `millis() - lastUpdate > 5000` checks if more than 5000ms (5 seconds) have passed. `millis()` returns the number of milliseconds since the board powered on.
- `pet.hunger--` uses the [`--` operator](https://cplusplus.com/doc/tutorial/operators/) to decrement by 1. Every 5 seconds, the pet gets slightly hungrier, sadder, and more tired.
- `if (pet.hunger < 0) pet.hunger = 0;` is **clamping**: we prevent stats from going below zero. Without this, hunger could hit -50, which makes no sense.
- `lastUpdate = millis();` resets the timer so the next update happens 5 seconds from *now*.

<details>
<summary>What is non-blocking timing?</summary>

This `millis()` pattern is fundamental to embedded programming. It's how you schedule periodic tasks without blocking the CPU. You'll see this exact pattern in [Arduino's BlinkWithoutDelay example](https://docs.arduino.cc/built-in-examples/digital/BlinkWithoutDelay/).

</details>

## Step 12: Reading Button Input

The buttons are wired active-low. Read them with [`digitalRead()`](https://docs.arduino.cc/language-reference/en/functions/digital-io/digitalRead/) and debounce to prevent repeated triggers.

```cpp
unsigned long lastButtonPress = 0;

void checkButtons() {
  if (millis() - lastButtonPress < 200) return;  // debounce: ignore presses within 200ms

  if (digitalRead(BTN_LEFT) == LOW) {
    currentScreen = SCREEN_FEED;
    tone(BUZZER_PIN, 1000, 50);
    lastButtonPress = millis();
  }
  else if (digitalRead(BTN_MIDDLE) == LOW) {
    currentScreen = SCREEN_PLAY;
    tone(BUZZER_PIN, 1200, 50);
    lastButtonPress = millis();
  }
  else if (digitalRead(BTN_RIGHT) == LOW) {
    currentScreen = SCREEN_SLEEP;
    tone(BUZZER_PIN, 800, 50);
    lastButtonPress = millis();
  }
}
```

**Notes:**

- `unsigned long lastButtonPress = 0;` tracks the last time any button was pressed, used for debouncing.
- `if (millis() - lastButtonPress < 200) return;` is **debouncing**. Physical buttons "bounce" (make and break contact rapidly) when pressed, which can register as multiple presses. By ignoring any press within 200ms of the last one, we ensure one press = one action.
- `digitalRead(BTN_LEFT) == LOW` reads the pin state. Because the buttons are active-low, `LOW` means the button is currently being pressed.
- `currentScreen = SCREEN_FEED;` sets the state but doesn't act on it. The actual logic runs in Step 13, keeping input detection and action execution separate.
- [`tone(BUZZER_PIN, 1000, 50);`](https://docs.arduino.cc/language-reference/en/functions/advanced-io/tone/) plays a short beep (1000Hz for 50ms) as audible feedback.

<details>
<summary>What is debouncing?</summary>

When you press a button, the contacts bounce for a few milliseconds, creating rapid on/off signals. The 200ms cooldown timer filters these out so one press registers once.

</details>

**Button mapping:**

| Button | Action | State Transition |
|---|---|---|
| Left | Feed the pet | → `SCREEN_FEED` |
| Middle | Play with pet | → `SCREEN_PLAY` |
| Right | Put pet to sleep | → `SCREEN_SLEEP` |

## Step 13: Screen Logic

Each screen modifies the pet's stats and returns to the main screen. Actions are one-shot: press feed, hunger goes up, done.

```cpp
void handleScreenLogic() {
  switch(currentScreen) {

    case SCREEN_FEED:
      pet.hunger += 10;
      if (pet.hunger > 100) pet.hunger = 100;
      currentScreen = SCREEN_MAIN;
      break;

    case SCREEN_PLAY:
      pet.happiness += 10;
      pet.energy -= 5;
      if (pet.happiness > 100) pet.happiness = 100;
      if (pet.energy < 0) pet.energy = 0;
      currentScreen = SCREEN_MAIN;
      break;

    case SCREEN_SLEEP:
      pet.energy += 15;
      if (pet.energy > 100) pet.energy = 100;
      currentScreen = SCREEN_MAIN;
      break;

    case SCREEN_MAIN:
      break;  // do nothing, just display stats
  }
}
```

**Notes:**

- [`switch(currentScreen)`](https://docs.arduino.cc/language-reference/en/structure/control-structure/switchCase/) selects behavior based on the current UI state.
- `pet.hunger += 10;` uses the [`+=` operator](https://cplusplus.com/doc/tutorial/operators/) to add 10 to the current value. Feeding restores 10 hunger points.
- `if (pet.hunger > 100) pet.hunger = 100;` is **upper clamping**: stats can't exceed 100. This is the mirror of the lower clamping in `updatePet()`.
- `pet.energy -= 5;`: playing increases happiness but costs energy.
- `currentScreen = SCREEN_MAIN;` returns to main after the action completes. This makes each action a one-shot: the player must actively choose to do something again.
- Each `case` ends with [`break`](https://docs.arduino.cc/language-reference/en/structure/control-structure/break/) to prevent fall-through.

<details>
<summary>Why does SCREEN_MAIN do nothing?</summary>

`SCREEN_MAIN` only renders stats; actions happen in the other states.

</details>

## Step 14: Pet Sprites

Create 1-bit sprites for the pet using [draw-to-bit](https://draw-to-bit.vercel.app/), which exports pixel art as C byte arrays.

You need at least a few expressions so the sprite reflects the pet's stats. Example 16x16 sprites:

```cpp
// Example: Happy face (all stats above 50)
const unsigned char PROGMEM petHappy[] = {
  0b00000000, 0b00000000,
  0b00011111, 0b11111000,
  0b00100000, 0b00000100,
  0b01000000, 0b00000010,
  0b01001100, 0b00110010,
  0b01001100, 0b00110010,
  0b01000000, 0b00000010,
  0b01000000, 0b00000010,
  0b01000100, 0b00100010,
  0b01000011, 0b11000010,
  0b01000000, 0b00000010,
  0b00100000, 0b00000100,
  0b00011111, 0b11111000,
  0b00000000, 0b00000000,
  0b00000000, 0b00000000,
  0b00000000, 0b00000000
};

// Example: Sad face (any stat below 30)
const unsigned char PROGMEM petSad[] = {
  0b00000000, 0b00000000,
  0b00011111, 0b11111000,
  0b00100000, 0b00000100,
  0b01000000, 0b00000010,
  0b01001100, 0b00110010,
  0b01001100, 0b00110010,
  0b01000000, 0b00000010,
  0b01000000, 0b00000010,
  0b01000000, 0b00000010,
  0b01000011, 0b11000010,
  0b01000100, 0b00100010,
  0b00100000, 0b00000100,
  0b00011111, 0b11111000,
  0b00000000, 0b00000000,
  0b00000000, 0b00000000,
  0b00000000, 0b00000000
};

// Example: Neutral face (everything else)
const unsigned char PROGMEM petNeutral[] = {
  0b00000000, 0b00000000,
  0b00011111, 0b11111000,
  0b00100000, 0b00000100,
  0b01000000, 0b00000010,
  0b01001100, 0b00110010,
  0b01001100, 0b00110010,
  0b01000000, 0b00000010,
  0b01000000, 0b00000010,
  0b01000111, 0b11100010,
  0b01000000, 0b00000010,
  0b01000000, 0b00000010,
  0b00100000, 0b00000100,
  0b00011111, 0b11111000,
  0b00000000, 0b00000000,
  0b00000000, 0b00000000,
  0b00000000, 0b00000000
};

// Example: Sleeping face (closed eyes)
const unsigned char PROGMEM petSleep[] = {
  0b00000000, 0b00000000,
  0b00011111, 0b11111000,
  0b00100000, 0b00000100,
  0b01000000, 0b00000010,
  0b01001111, 0b01110010,
  0b01000000, 0b00000010,
  0b01000000, 0b00000010,
  0b01000000, 0b00000010,
  0b01000011, 0b11000010,
  0b01000000, 0b00000010,
  0b01000000, 0b00000010,
  0b00100000, 0b00000100,
  0b00011111, 0b11111000,
  0b00000000, 0b00000000,
  0b00000000, 0b00000000,
  0b00000000, 0b00000000
};
```

**Notes:**

- `const unsigned char PROGMEM` stores the bitmap in flash instead of RAM. See [`PROGMEM`](https://docs.arduino.cc/language-reference/en/variables/utilities/PROGMEM/).
- Each row is two bytes (16 bits = 16 pixels wide). A `1` bit lights up that pixel, a `0` bit leaves it dark.
- Four example expressions are defined above. Replace them with your own sprites from [draw-to-bit](https://draw-to-bit.vercel.app/).

<details>
<summary>Can I make the pet sprite bigger?</summary>

Yes. Use a larger bitmap (e.g., 32x32) and update the `drawBitmap()` dimensions to match. Larger sprites use more flash and screen space.

</details>

## Step 15: Display Function (OLED Rendering)

Draws the sprite and stat bars. Sprite selection is based on current stats.

```cpp
void render() {
  display.clearDisplay();

  // Choose the right sprite based on pet stats
  const unsigned char* sprite;
  if (pet.hunger < 30 || pet.happiness < 30 || pet.energy < 30) {
    sprite = petSad;
  } else if (pet.hunger > 50 && pet.happiness > 50 && pet.energy > 50) {
    sprite = petHappy;
  } else {
    sprite = petNeutral;
  }

  // Draw the pet sprite (centered horizontally, near the top)
  display.drawBitmap(56, 2, sprite, 16, 16, SSD1306_WHITE);

  // Draw stat bars below the pet
  display.setTextSize(1);

  display.setCursor(0, 24);
  display.print("HUN ");
  drawBar(24, 24, pet.hunger);

  display.setCursor(0, 34);
  display.print("HAP ");
  drawBar(24, 34, pet.happiness);

  display.setCursor(0, 44);
  display.print("ENG ");
  drawBar(24, 44, pet.energy);

  // Button labels at the bottom
  display.setCursor(0, 56);
  display.println("[Feed] [Play] [Sleep]");

  display.display();
}

// Draws a stat bar: empty rectangle with a filled portion based on value (0 to 100)
void drawBar(int x, int y, int value) {
  int barWidth = 100;
  int barHeight = 6;
  int fillWidth = map(value, 0, 100, 0, barWidth);

  display.drawRect(x, y, barWidth, barHeight, SSD1306_WHITE);       // outline
  display.fillRect(x, y, fillWidth, barHeight, SSD1306_WHITE);      // filled portion
}
```

**Notes:**

- Sprite is chosen by `if/else`: any stat below 30 = sad, all above 50 = happy, otherwise neutral.
- [`display.drawBitmap()`](https://learn.adafruit.com/adafruit-gfx-graphics-library/graphics-primitives) draws a 1-bit bitmap. `56, 2` centers the 16px sprite on the 128px-wide screen.
- `drawBar()` draws an outline with [`drawRect()`](https://learn.adafruit.com/adafruit-gfx-graphics-library/graphics-primitives) and fills it proportionally with `fillRect()`.
- [`map()`](https://docs.arduino.cc/language-reference/en/functions/math/map/) scales the stat value to the bar's pixel width.
- `display.display()` pushes the buffer to the OLED.

<details>
<summary>Why do we clear and redraw every frame?</summary>

The SSD1306 uses a framebuffer. Without clearing first, old pixels remain and overlap new content. The clear → draw → display pattern is standard for frame-based rendering.

</details>

## Step 16: Main Loop

[`loop()`](https://docs.arduino.cc/language-reference/en/structure/sketch/loop/) runs repeatedly after `setup()` finishes. It reads input, updates state, and redraws the display.

```cpp
void loop() {
  checkButtons();       // 1. Read input
  updatePet();          // 2. Update state over time
  handleScreenLogic();  // 3. Process actions
  render();             // 4. Display results
  delay(100);           // 5. Short pause
}
```

**Loop order:**

```
┌──────────────────────────────────────────────────────┐
│                    GAME LOOP                         │
│                                                      │
│  ┌─────────┐   ┌────────┐   ┌───────┐   ┌────────┐ │
│  │  INPUT   │──▶│ UPDATE │──▶│ LOGIC │──▶│ RENDER │ │
│  │ (read    │   │ (decay │   │ (feed,│   │ (draw  │ │
│  │ buttons) │   │ stats) │   │ play) │   │ OLED)  │ │
│  └─────────┘   └────────┘   └───────┘   └────────┘ │
│       ▲                                      │      │
│       └──────────── delay(100) ──────────────┘      │
└──────────────────────────────────────────────────────┘
```

1. **Input**: Read buttons, set `currentScreen`.
2. **Update**: Decay stats based on elapsed time.
3. **Logic**: Execute the selected action (feed/play/sleep), return to main.
4. **Render**: Draw the frame.
5. **Pause**: `delay(100)` limits refresh rate while keeping input responsive.

<details>
<summary>What is a game loop?</summary>

This is a standard [game loop](https://gameprogrammingpatterns.com/game-loop.html) pattern (input → update → render), common in interactive programs.

</details>

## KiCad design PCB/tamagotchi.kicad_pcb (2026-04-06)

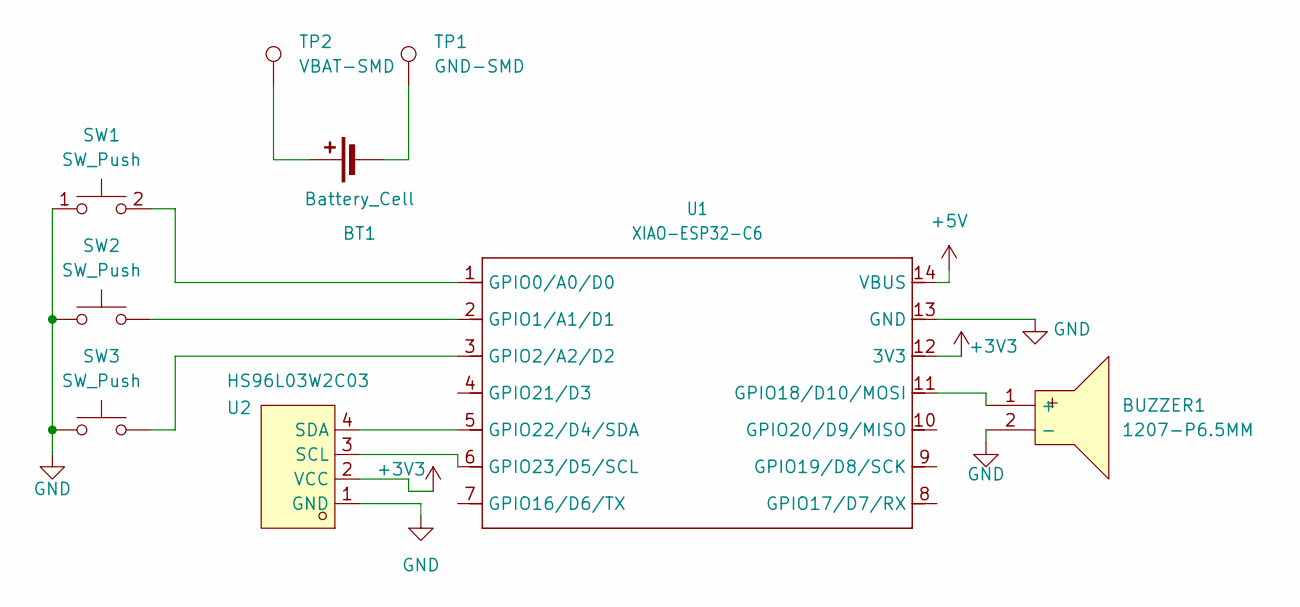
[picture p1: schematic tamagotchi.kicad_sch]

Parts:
BT1: Battery_Cell; PinHeader_1x02_P2.54mm_Vertical
BUZZER1: 1207-P6.5MM; BUZ-TH_BD12.5-P6.50-D1.4; LCSC Part C49246964
SW1, SW2, SW3: SW_Push; SW-TH_4P-L4.5-W4.5-P3.00-LS4.8
TP1: GND-SMD; TestPoint_Pad_D2.0mm
TP2: VBAT-SMD; TestPoint_Pad_D2.0mm
U1: XIAO-ESP32-C6; XIAO-ESP32C6-DIP
U2: HS96L03W2C03; OLED-TH_L27.8-W27.2-P2.54_C9900033791; LCSC Part C5248080

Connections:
+3V3: U1.12 (3V3), U2.2 (VCC)
+5V: U1.14 (VBUS)
GND: BUZZER1.2 (-), SW1.1, SW2.1, SW3.1, U1.13 (GND), U2.1 (GND)
unnamed: BT1.1 (+), TP2.1 (1_1)
unnamed: BT1.2 (-), TP1.1 (1_1)
unnamed: BUZZER1.1 (+), U1.11 (GPIO18/D10/MOSI)
unnamed: SW1.2, U1.1 (GPIO0/A0/D0)
unnamed: SW2.2, U1.2 (GPIO1/A1/D1)
unnamed: SW3.2, U1.3 (GPIO2/A2/D2)
unnamed: U1.5 (GPIO22/D4/SDA), U2.4 (SDA)
unnamed: U1.6 (GPIO23/D5/SCL), U2.3 (SCL)

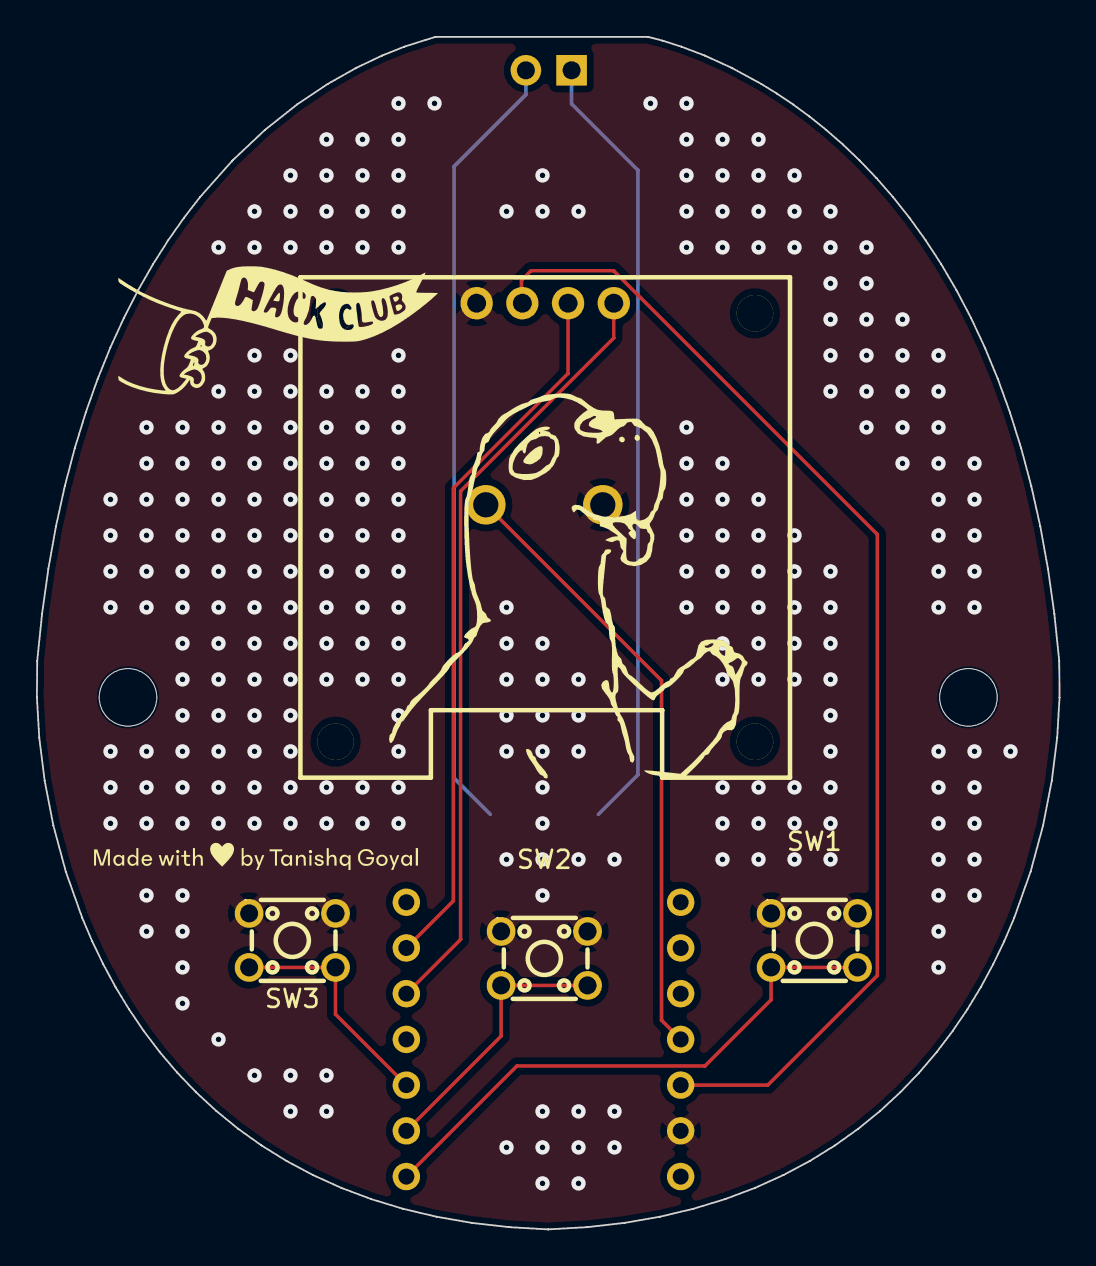
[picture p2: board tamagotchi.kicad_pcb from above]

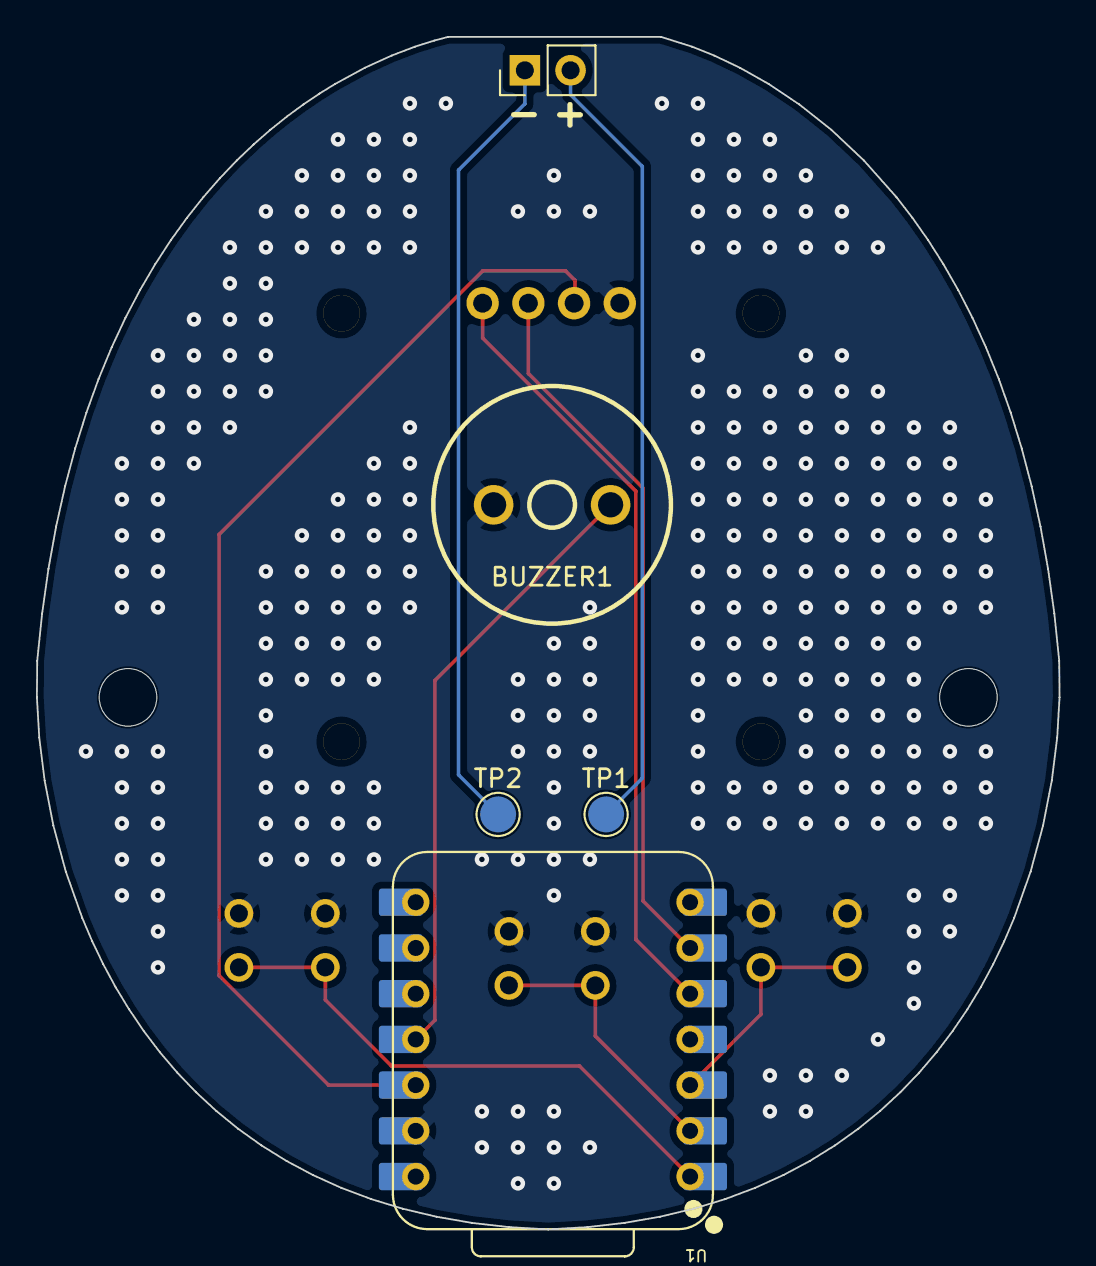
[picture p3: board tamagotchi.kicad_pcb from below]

Board: 2 copper layers, 56.8 x 66.2 mm, 9 parts (5 on the bottom side), 10 nets.

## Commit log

2026-02-12 Enhance PCB tutorial with detailed steps and images
    Expanded tutorial with detailed steps for creating a PCB using KiCad, including wiring, design rules check, and GitHub integration.
2026-02-16 base file uploades
    [tamagotchi.kicad_pcb, tamagotchi.kicad_sch]
2026-02-16 Add BOM to readme
2026-02-16 Add .csv BOM
    [BOM.csv]
2026-02-16 Add detailed KiCad installation instructions and shortcuts to tutorial
2026-02-16 Remove redundant details section from KiCad installation instructions
2026-02-17 Fix BOM.csv formatting and remove empty line
    [BOM.csv]
2026-02-17 Fix typo in OLED Display component name
    [BOM.csv]
2026-02-18 Add Tamagotchi game implementation with OLED display and button controls
    - Implemented pet model with hunger, happiness, energy, and age attributes.
    - Created state machine for different screens: main, feed, play, and sleep.
    - Added sprite graphics for pet states (happy, sad, neutral, sleep).
    - Developed functions for updating pet status, handling button inputs, and rendering display.
    - Integrated buzzer feedback for button presses.
    - Initialized pet attributes in setup and managed game loop in main loop.
    [Tamagotchi.ino]
2026-03-13 Update Gerber files for PCB design
2026-04-06 Fixing schematic
2026-04-06 Refactor code structure for improved readability and maintainability
    [tamagotchi.kicad_pcb, tamagotchi.kicad_sch]
2026-04-06 Add section for Button Footprint Mismatch in PCB tutorial
2026-04-07 Update KiCad getting started link
2026-04-09 Add link to Onshape tutorial in PCB export section
2026-04-11 Correct MCU reference from C6 to C3 in tutorial
    Updated references from XIAO-ESP32-C6 to XIAO-ESP32-C3 for accuracy in the tutorial.
2026-04-12 Update BOM.csv with new item details and format
    [BOM.csv]
2026-06-04 Add voltage information, as well as useful diagrams
